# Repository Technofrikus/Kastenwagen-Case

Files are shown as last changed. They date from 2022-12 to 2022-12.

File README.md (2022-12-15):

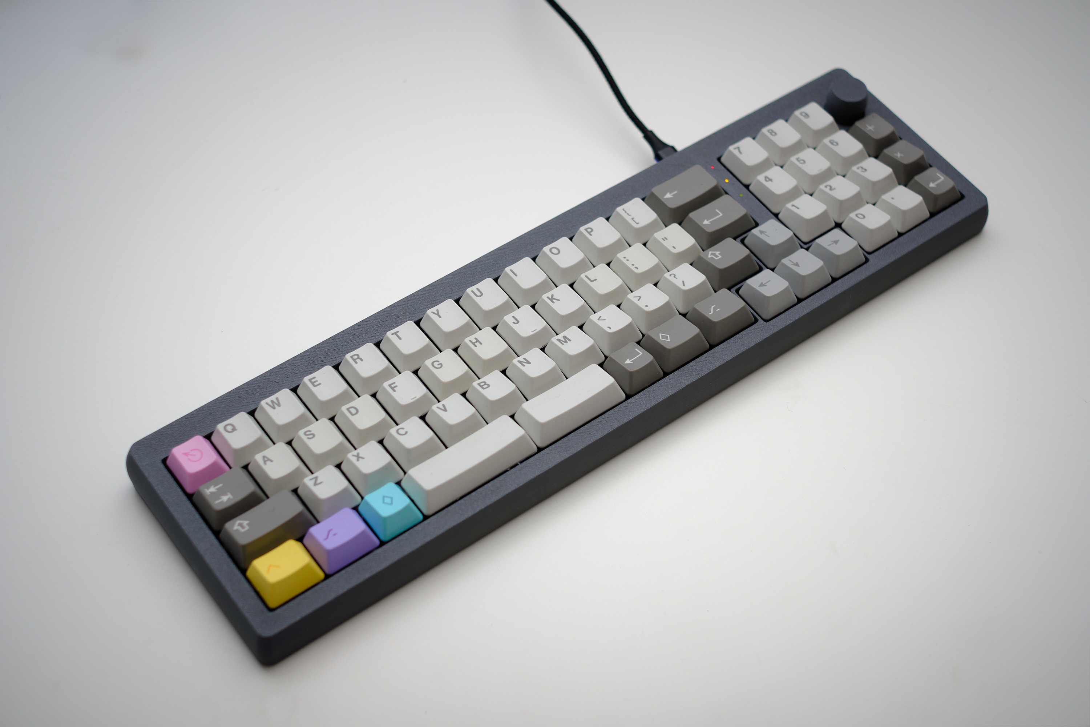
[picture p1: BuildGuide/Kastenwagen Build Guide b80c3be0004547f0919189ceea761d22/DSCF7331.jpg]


# Kastenwagen-Case
Printable Case for the Kastenwagen by NoPunIn10Did
PCB and Plate available here: [Kastenwagen on Github](https://github.com/nopunin10did/kastenwagen)

Both versions for the big and small (without Numpad) Kastenwagen are available. __Kastenwagen1840__ and __Kastenwagen48__

This is intended to be a drop-in replacement for the Kastenwagen PCB and Plate. So it is not necessary to desolder anything. 

If you order the PCB etc yourself: you only need the switch-plate for this case, not the bottom plate. And no standoffs etc.

Please note: you HAVE to solder the MCU flat on the PCB, otherise the cutout in the case will not align with the USB.

It logo on the bottom is meant to be printed in one go with changing the filament, not glued in. There is no gap between these, so glueing will probably not work. Check [this instrucable](https://www.instructables.com/Poor-Mans-MMU-Multicolor-Printing-With-Single-Extr/) how to do this with only one Extruder.

## Print instructions
- Case, knob and logo can be printed in simple PLA
  - Normal amount of perimeters and infill is enough, more feels better and sturdier
  - Print the top upside down, the bottom normal side up
- The included printed feet are nice but you can also not print them and glue standard feet somewhere else on the case.
  - Print the feet with 60A TPU, so they are very soft and really help with slipping. Harder TPUs are still relatively slippy. I used Recreus
Filaflex 60A.

## __[Build Guide](https://github.com/Technofrikus/Kastenwagen-Case/tree/main/BuildGuide)__ 

## Hardware needed:
| Qty  | Hardware |
| --- | --- |
| 6x  | M2 x 4mm brass inserts for the top |
| 6x  | M2x16 screws |
| 3x  | ~14mm long, 1mm diameter, optical fiber made from plastic |
| 24x  | ~20mm Gaskets, 2mm thickness EPDM, ~5mm width |
| 1x  | 1mm drill for the light guide holes |

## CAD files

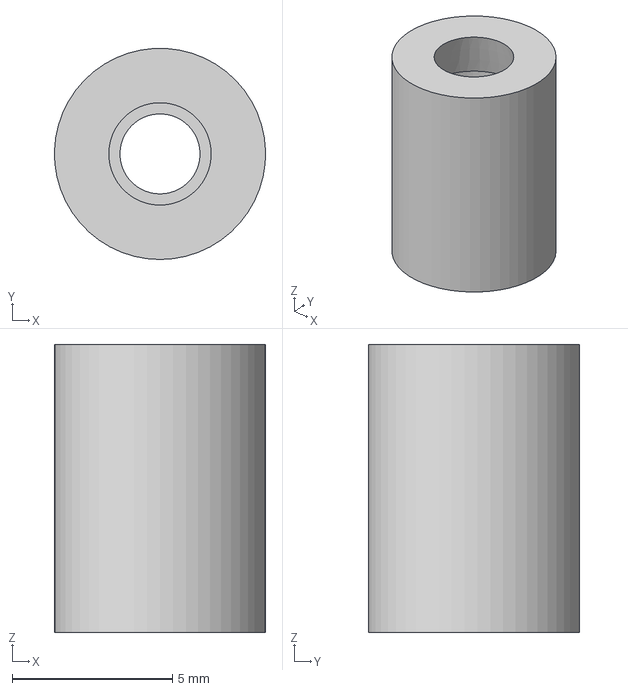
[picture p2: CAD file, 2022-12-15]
Foot/Foot long M2.step
6.60 x 6.59 x 9.00 mm

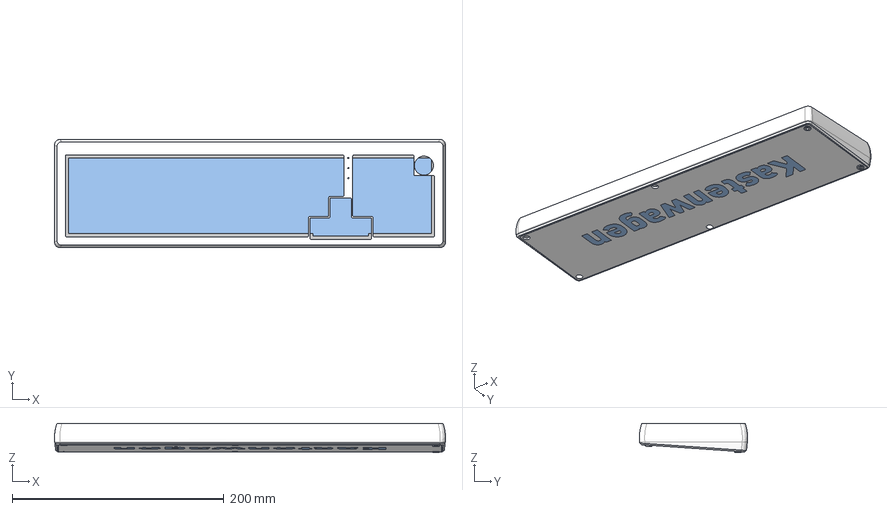
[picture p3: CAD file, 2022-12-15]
Kastenwagen1840/STEP/Kastenwagen Case 1840 with encoder.step
369.2 x 102.3 x 27.5 mm
Plate
USB Connector Type C female 6pin
Oberteil
Schriftzug
lang2
kurz2

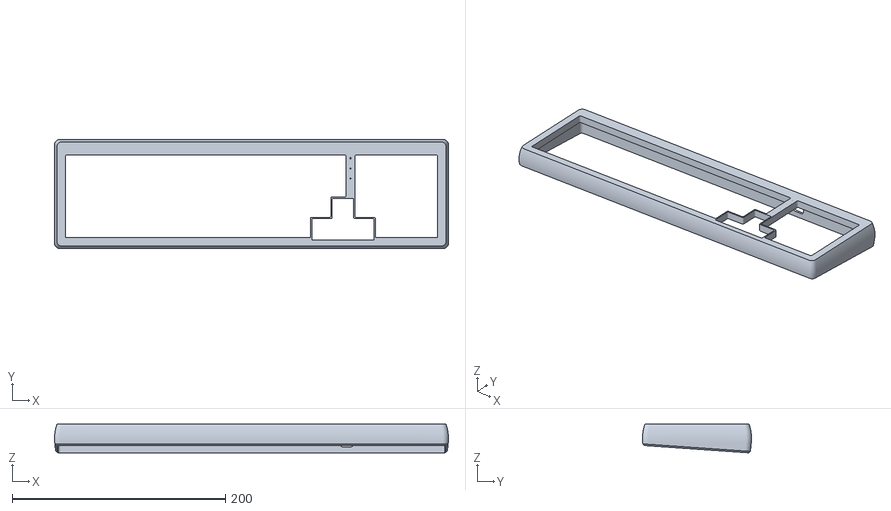
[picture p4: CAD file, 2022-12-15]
Kastenwagen1840/STL/Kastenwagen Top no Encoder.stl
369.3 x 102.3 x 26.9

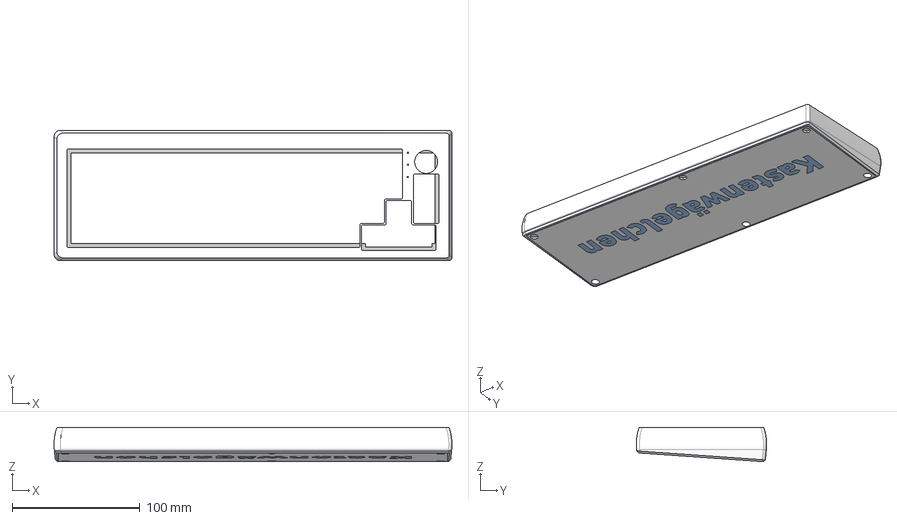
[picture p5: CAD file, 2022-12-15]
Kastenwagen48/STEP/Kastenwägelchen with Encoder.step
312.0 x 102.2 x 26.9 mm
Plate
Oberteil
Schriftzug

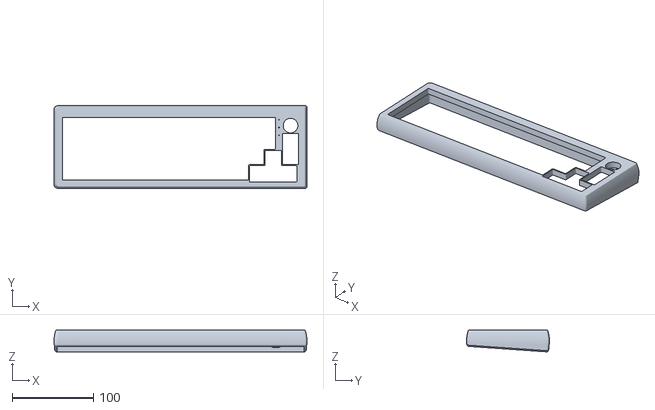
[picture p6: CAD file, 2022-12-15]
Kastenwagen48/STL/Kastenwägelchen Top with Encoder.stl
312.0 x 102.3 x 26.9

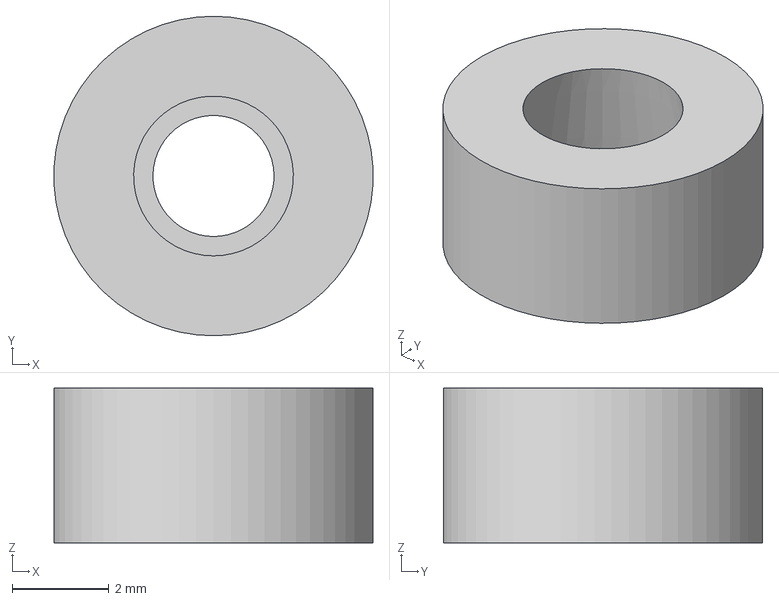
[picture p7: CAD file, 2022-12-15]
Foot/Foot short M2.step
6.59 x 6.60 x 3.20 mm

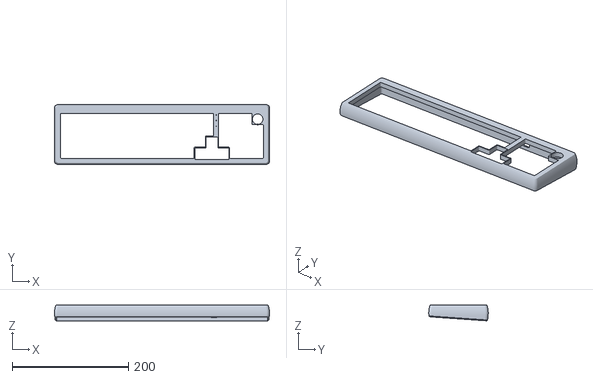
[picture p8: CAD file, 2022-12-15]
Kastenwagen1840/STL/Kastenwagen Top with Encoder.stl
369.3 x 102.3 x 26.9

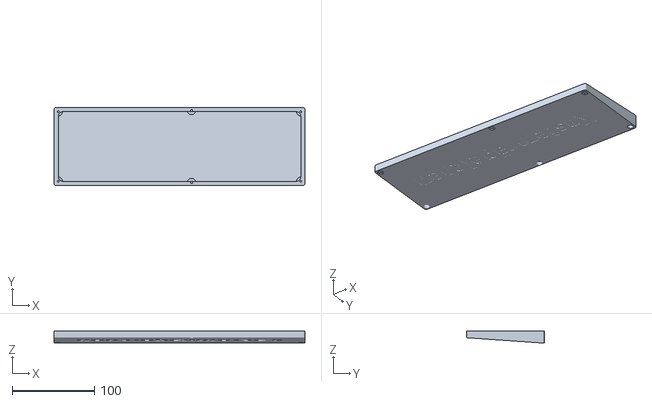
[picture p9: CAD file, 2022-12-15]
Kastenwagen48/STL/Kastenwägelchen Bottom.stl
304.7 x 94.9 x 15.0

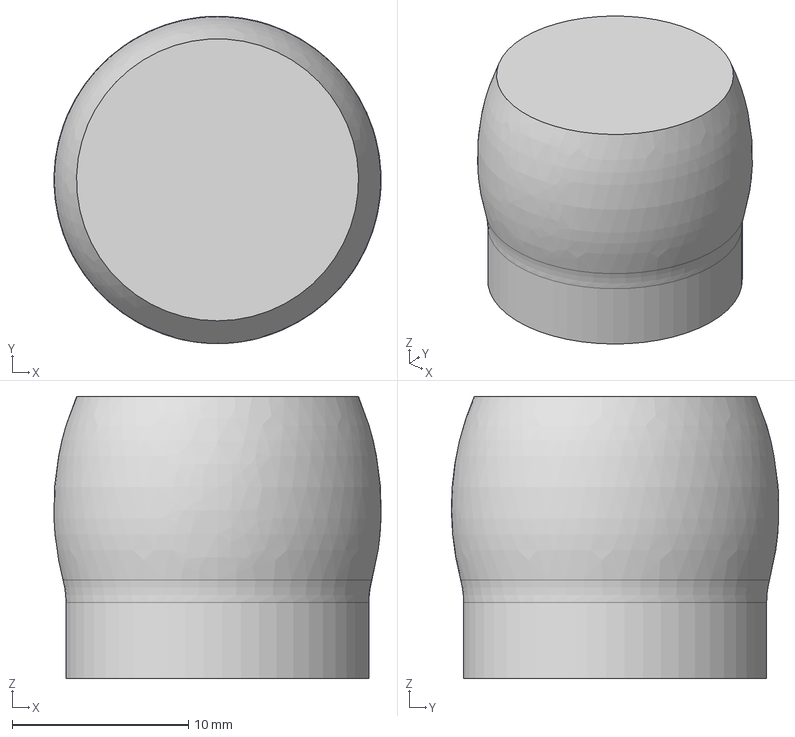
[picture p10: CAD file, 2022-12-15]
Kastenwagen1840/STEP/Knob.step
18.6 x 18.6 x 16.0 mm

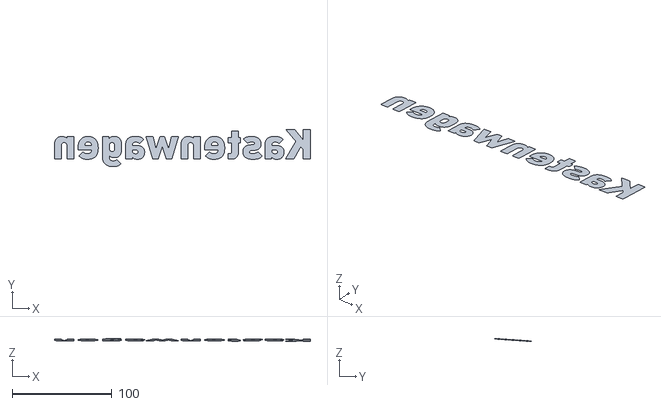
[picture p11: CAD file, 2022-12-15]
Kastenwagen1840/STL/Kastenwagen Bottom logo.stl
257.0 x 37.5 x 2.87

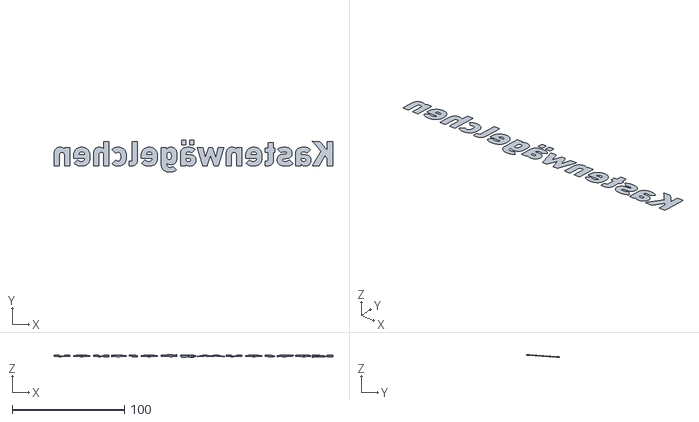
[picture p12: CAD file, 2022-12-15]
Kastenwagen48/STL/Kastenwägelchen logo.stl
248.7 x 28.8 x 2.26

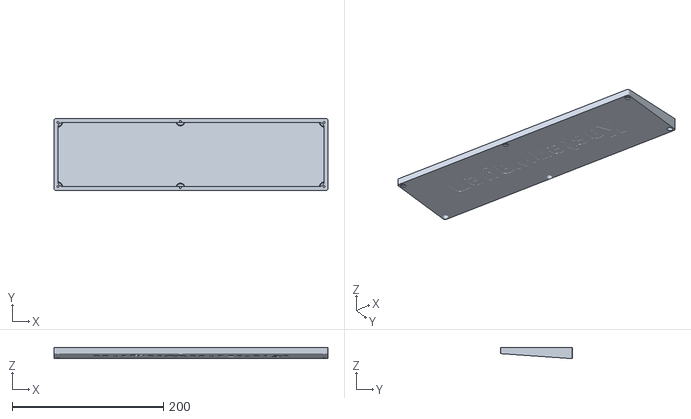
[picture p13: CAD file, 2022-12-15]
Kastenwagen1840/STL/Kastenwagen Bottom.stl
361.9 x 94.9 x 15.0

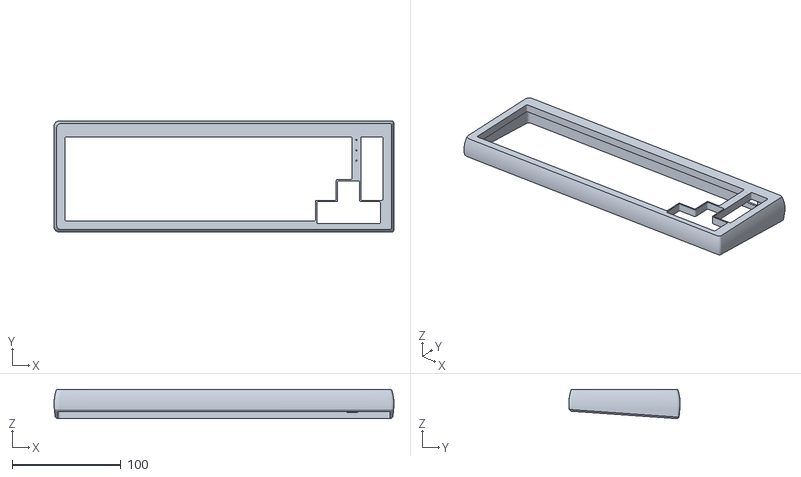
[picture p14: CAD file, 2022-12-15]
Kastenwagen48/STL/Kastenwägelchen Top no Encoder.stl
312.0 x 102.3 x 26.9

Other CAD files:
Kastenwagen1840/STEP/Kastenwagen Case 1840 no encoder.step
Kastenwagen48/STEP/Kastenwägelchen no Encoder.step
Foot/Foot long M2.stl
Foot/Foot short M2.stl
Kastenwagen48/STL/Knob.stl

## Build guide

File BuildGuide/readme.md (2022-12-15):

# Kastenwagen Build Guide



# Dissassemble if necessary

**Disassemble your existing Kastenwagen**, so only the top plate with switches in it and the PCB are still there. No standoffs, no bottom plate, no screws. No need to desolder anything.

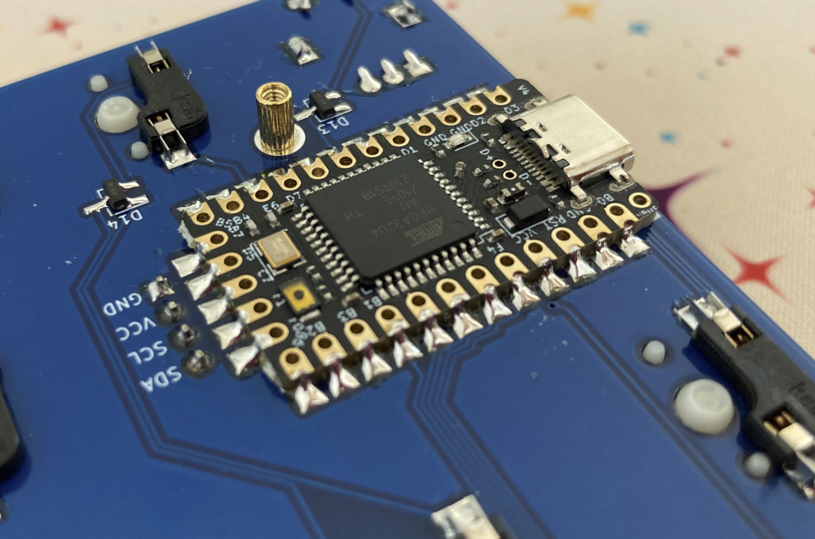
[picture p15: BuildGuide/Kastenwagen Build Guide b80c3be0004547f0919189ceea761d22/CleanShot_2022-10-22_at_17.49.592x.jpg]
CleanShot 2022-10-22 at 17.49.59@2x.jpg


The MCU *has to be* soldered **flat** on to the PCB (different PCB in the picture). Dont use any standoffs.

# Assembly

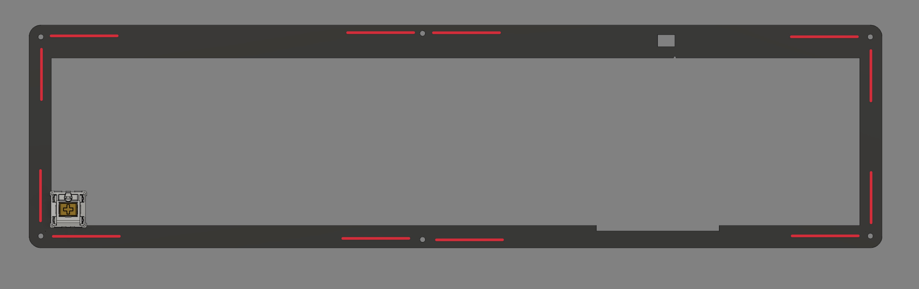
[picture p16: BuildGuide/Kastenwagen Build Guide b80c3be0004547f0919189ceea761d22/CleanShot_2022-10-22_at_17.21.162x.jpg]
CleanShot 2022-10-22 at 17.21.16@2x.jpg


1. First **stick the gaskets on the Kastenwagen plate** like in the picture above, at the red lines. So around the screw holes. (the plate in the picture is missing the switch cutouts)
2. **On both sides** of the plate, please.
3. **Put the screws through the rubber feet**. Put the screw in from the smooth side of the feet. The other one has this rough texture from the print bed (like the top of the case itself). This is the side of the feet that goes into the keyboard.
    1. 3x long rubber part
    2. 3x short rubber part
    
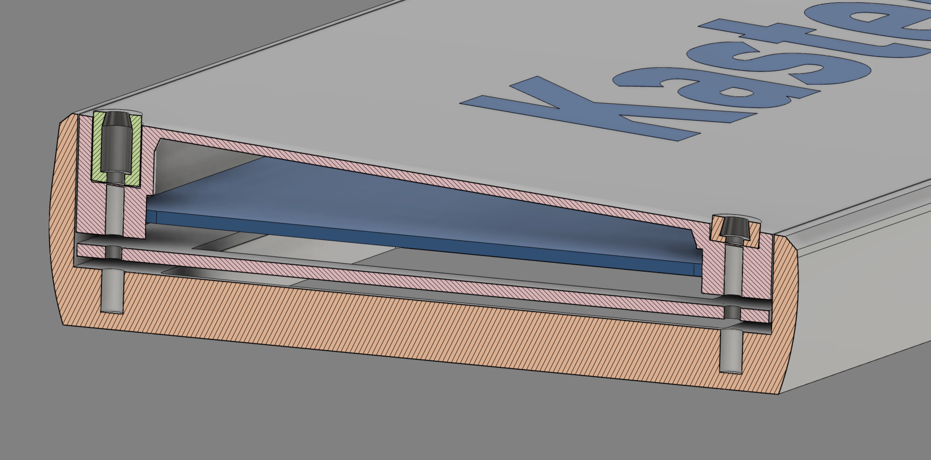
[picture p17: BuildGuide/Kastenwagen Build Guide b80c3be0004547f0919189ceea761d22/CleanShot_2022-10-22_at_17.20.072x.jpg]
CleanShot 2022-10-22 at 17.20.07@2x.jpg
    
    
4. **Put the case together** with the plate in the middle, screw in the screws with the feet attached.
    1. BE CAREFUL! **Just tighten the screws until the bottom of the case is smooth with top.** There is no “stop”, you dont feel the screws getting tighter. If you continue to tighten the screws they will damage the top part of the case which will be very visible!

5. **Cut the light guides to length**. Should be around **13,8mm.** Best use a knife, make a mark and break them, so both ends are flat and not squashed. 
    
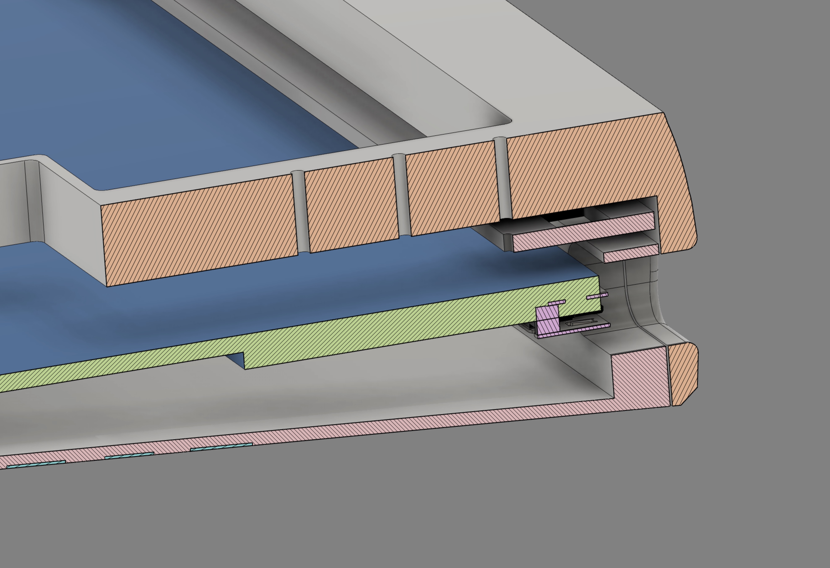
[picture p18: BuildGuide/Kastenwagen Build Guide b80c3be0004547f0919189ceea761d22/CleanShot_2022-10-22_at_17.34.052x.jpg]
CleanShot 2022-10-22 at 17.34.05@2x.jpg
    
    
    1. Drill the three holes with a 1mm drill, so the light guide fits in. The holes are designed to be too small. Be careful while drilling to not make the holes bigger. Drill slowly.
    2. Rub them a bit in glue stick. You can also use other glue, but especially **super glue leaves visible marks on the print**, so be very careful or just use glue stick. 
    3. Push them in from the top. They have to go through the Plate onto the LED on the PCB to work properly. If you cant push them in completely, rotate them a bit so they find the hole in the Plate. 
6. **Flash this latest Firmware** on the board so you can use all the nice Features with VIAL, like Key Overrides, TapDance and Combos.

[20221010_nopunin10did_kastenwagen_vial.hex](Kastenwagen%20Build%20Guide%20b80c3be0004547f0919189ceea761d22/20221010_nopunin10did_kastenwagen_vial.hex)

Happy Typing!

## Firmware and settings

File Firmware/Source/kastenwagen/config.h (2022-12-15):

/* Copyright 2021 W. Alex Ronke, a.k.a. NoPunIn10Did (w.alex.ronke@gmail.com)
 *
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
 * You should have received a copy of the GNU General Public License
 * along with this program.  If not, see <http://www.gnu.org/licenses/>.
 */

#pragma once

#include "config_common.h"

/* USB Device descriptor parameter */
#define VENDOR_ID           0x4E50  // "NP"
#define PRODUCT_ID          0x4B57  // "KW"
#define DEVICE_VER          0x0001
#define MANUFACTURER        NoPunIn10Did
#define PRODUCT             Kastenwagen

/* key matrix size */
#define MATRIX_ROWS         8
#define MATRIX_COLS         9

/* key matrix pins */
#define MATRIX_ROW_PINS     { B4, B5, B7, D5, C7, F1, F0, B6 }
#define MATRIX_COL_PINS     { F4, F5, F6, F7, B1, B3, B2, E6, D7 }

/* VIAL */
#define VIAL_KEYBOARD_UID {0x78, 0x6B, 0xDC, 0xF8, 0x63, 0x56, 0xEA, 0x9A}
#define VIAL_UNLOCK_COMBO_ROWS {0,1} 
#define VIAL_UNLOCK_COMBO_COLS {0,2}
#define VIAL_KEY_OVERRIDE_ENTRIES 12
#define VIAL_TAP_DANCE_ENTRIES 5
#define VIAL_COMBO_ENTRIES 6


/* Indicator LEDs */
#define LED_INDICATOR_TOP   B0
#define LED_INDICATOR_MID   D4
#define LED_INDICATOR_BOT   C6

/* Rotary encoder rotation pins */
#define ENCODERS_PAD_A      { D0, D3 }
#define ENCODERS_PAD_B      { D1, D2 }


/* COL2ROW or ROW2COL */
#define DIODE_DIRECTION     COL2ROW

/* Set 0 if debouncing isn't needed */
#define DEBOUNCE            5

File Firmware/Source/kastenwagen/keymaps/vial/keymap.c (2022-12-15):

/* Copyright 2021 W. Alex Ronke, a.k.a. NoPunIn10Did (w.alex.ronke@gmail.com)
 *
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
 * You should have received a copy of the GNU General Public License
 * along with this program.  If not, see <http://www.gnu.org/licenses/>.
 */

#include QMK_KEYBOARD_H

#define L2_SPC      LT(2,KC_SPC)
#define L3_SPC      LT(3,KC_SPC)
#define L3_PENT     LT(3,KC_PENT)
#define RWINALT     RALT_T(KC_RGUI)
#define ISO_LT      KC_NUBS
#define ISO_GT      LSFT(KC_NUBS)

bool is_alt_tab_active = false;
uint16_t alt_tab_timer = 0;

#if defined(ENCODER_MAP_ENABLE)
const uint16_t PROGMEM encoder_map[][NUM_ENCODERS][2] = {
    [0] =  { ENCODER_CCW_CW(KC_VOLD, KC_VOLU)  },
    [1] =  { ENCODER_CCW_CW(RGB_HUD, RGB_HUI)},
    [2] =  { ENCODER_CCW_CW(RGB_VAD, RGB_VAI)  },
    [3] = { ENCODER_CCW_CW(RGB_RMOD, RGB_MOD) },
};
#endif



const uint16_t PROGMEM keymaps[][MATRIX_ROWS][MATRIX_COLS] = {

[0] = LAYOUT_1840(

    KC_ESC ,KC_Q   ,KC_W   ,KC_E   ,KC_R   ,KC_T   ,KC_Y   ,KC_U   ,KC_I   ,KC_O   ,KC_P   ,KC_LBRC,KC_BSPC      , KC_P7  ,KC_P8  ,KC_P9  ,KC_PMNS,
    KC_TAB   ,KC_A   ,KC_S   ,KC_D   ,KC_F   ,KC_G   ,KC_H   ,KC_J   ,KC_K   ,KC_L   ,KC_SCLN,KC_QUOT,KC_ENT     , KC_P4  ,KC_P5  ,KC_P6  ,KC_PPLS,
    KC_LSPO      ,KC_Z   ,KC_X   ,KC_C   ,KC_V   ,KC_B   ,KC_N   ,KC_M   ,KC_COMM,KC_DOT ,KC_SLSH,KC_RSPC ,KC_UP , KC_P1  ,KC_P2  ,KC_P3  ,KC_PAST,
    KC_LCTL  ,KC_LALT  ,MO(2)  ,L2_SPC               ,L3_SPC           ,MO(3)  ,RWINALT  ,MO(1)   ,KC_LEFT,KC_DOWN,KC_RGHT,KC_P0  ,KC_PDOT,L3_PENT  
    ),
[1] = LAYOUT_1840(
    RESET  ,KC_F1  ,KC_F2  ,KC_F3  ,KC_F4  ,KC_F5  ,KC_F6  ,KC_F7  ,KC_F8  ,KC_F9  ,KC_F10 ,KC_RBRC,KC_DEL       , KC_HOME,XXXXXXX,KC_PGUP,XXXXXXX,
    KC_CAPS  ,KC_F11 ,KC_F12 ,XXXXXXX,XXXXXXX,XXXXXXX,XXXXXXX,XXXXXXX,XXXXXXX,XXXXXXX,XXXXXXX,XXXXXXX,XXXXXXX    , XXXXXXX,XXXXXXX,XXXXXXX,KC_PAST,
    _______      ,XXXXXXX,XXXXXXX,KC_PSCR,KC_SLCK,KC_PAUS,KC_INS ,KC_APP ,KC_LGUI,KC_RGUI,XXXXXXX,_______ ,KC_PGUP,KC_END ,XXXXXXX,KC_PGDN,KC_PSLS,
    KC_RCTL  ,_______  ,_______,XXXXXXX              ,XXXXXXX          ,_______,_______  ,_______ ,KC_HOME,KC_PGDN,KC_END ,KC_INS ,KC_DEL ,KC_EQL   
    ),
[2] = LAYOUT_1840(
    KC_GRV ,KC_1   ,KC_2   ,KC_3   ,KC_4   ,KC_5   ,KC_6   ,KC_7   ,KC_8   ,KC_9   ,KC_0   ,KC_MINS,KC_EQL       , XXXXXXX,XXXXXXX,XXXXXXX,XXXXXXX,
    KC_TILD  ,KC_EXLM,KC_AT  ,KC_HASH,KC_DLR ,KC_PERC,KC_CIRC,KC_AMPR,KC_ASTR,KC_UNDS,KC_LBRC,KC_RBRC,KC_BSLS    , XXXXXXX,XXXXXXX,XXXXXXX,XXXXXXX,
    _______      ,ISO_LT ,XXXXXXX,XXXXXXX,XXXXXXX,XXXXXXX,XXXXXXX,XXXXXXX,XXXXXXX,XXXXXXX,XXXXXXX,_______ ,XXXXXXX,XXXXXXX,XXXXXXX,XXXXXXX,XXXXXXX,
    _______  ,_______  ,_______,XXXXXXX              ,XXXXXXX          ,_______,_______  ,_______ ,XXXXXXX,XXXXXXX,XXXXXXX,XXXXXXX,XXXXXXX,XXXXXXX  
    ),
[3] = LAYOUT_1840(
    KC_TILD,KC_EXLM,KC_AT  ,KC_HASH,KC_DLR ,KC_PERC,KC_CIRC,KC_AMPR,KC_ASTR,KC_LPRN,KC_RPRN,KC_UNDS,KC_PLUS      , KC_NLCK,KC_PSLS,KC_PAST,XXXXXXX,
    _______  ,XXXXXXX,XXXXXXX,XXXXXXX,XXXXXXX,XXXXXXX,XXXXXXX,XXXXXXX,XXXXXXX,XXXXXXX,KC_LCBR,KC_RCBR,KC_PIPE    , KC_PSCR,KC_SLCK,KC_PAUS,XXXXXXX,
    _______      ,ISO_GT ,XXXXXXX,XXXXXXX,XXXXXXX,XXXXXXX,XXXXXXX,XXXXXXX,XXXXXXX,XXXXXXX,XXXXXXX,_______ ,XXXXXXX,XXXXXXX,XXXXXXX,XXXXXXX,XXXXXXX,
    _______  ,_______  ,_______,XXXXXXX              ,XXXXXXX          ,_______,_______  ,_______ ,XXXXXXX,XXXXXXX,XXXXXXX,XXXXXXX,XXXXXXX,_______  
    )
};

void matrix_scan_user(void) {
    
    if (is_alt_tab_active) {
        if (timer_elapsed(alt_tab_timer) > 1250) {
            unregister_code(KC_LALT);
            is_alt_tab_active = false;
        }
    }
}

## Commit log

2022-12-15 All 3D
    [Foot long M2.step, Foot long M2.stl, Foot short M2.step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]
2022-12-15 Update readme.md
    Added drill instructions

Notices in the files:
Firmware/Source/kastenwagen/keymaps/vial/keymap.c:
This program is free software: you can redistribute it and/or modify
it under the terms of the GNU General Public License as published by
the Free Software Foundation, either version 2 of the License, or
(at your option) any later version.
